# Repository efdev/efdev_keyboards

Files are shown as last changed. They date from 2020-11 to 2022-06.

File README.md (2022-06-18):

# PCBs

# Firmware

Based on zmk.

Basic setup see https://zmk.dev/docs/development/setup .

Extend zmk west.yml remotes list with the following 

```
- name: microsoft
      url-base: https://github.com/microsoft
```
and the projects list with
```
- name: uf2
      remote: microsoft
      path: tools/uf2
      clone-depth: 1
```
and run `west update`

Build firmware `west build -p -b <board> -- -DBOARD_ROOT=<path to cloned repo>/Firmware`

Example: `west build -p -b akortho -- -DBOARD_ROOT=/home/efdev/Documents/Keyboards/Firmware`

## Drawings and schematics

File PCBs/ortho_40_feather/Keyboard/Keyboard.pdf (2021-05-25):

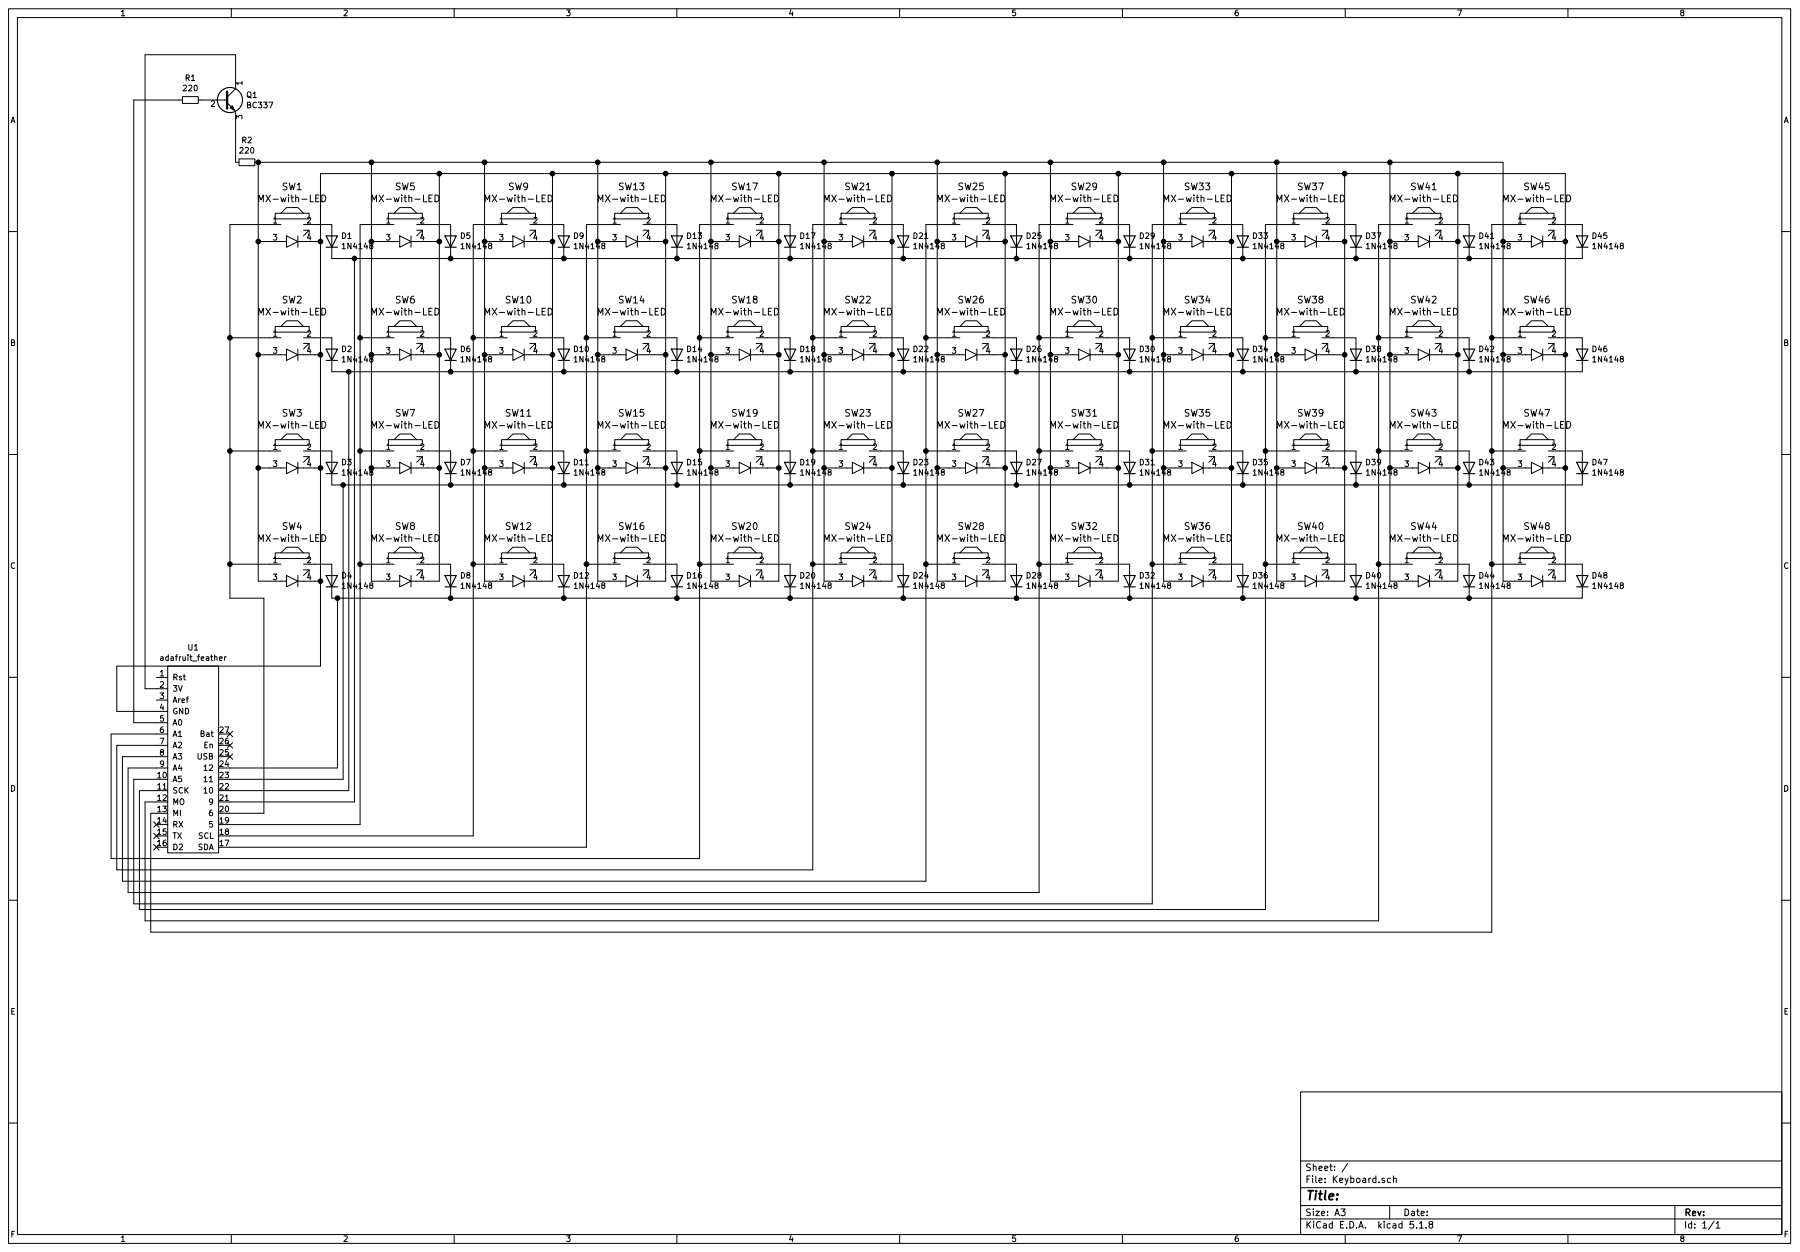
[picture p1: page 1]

File: Keyboard.sch Sheet: /

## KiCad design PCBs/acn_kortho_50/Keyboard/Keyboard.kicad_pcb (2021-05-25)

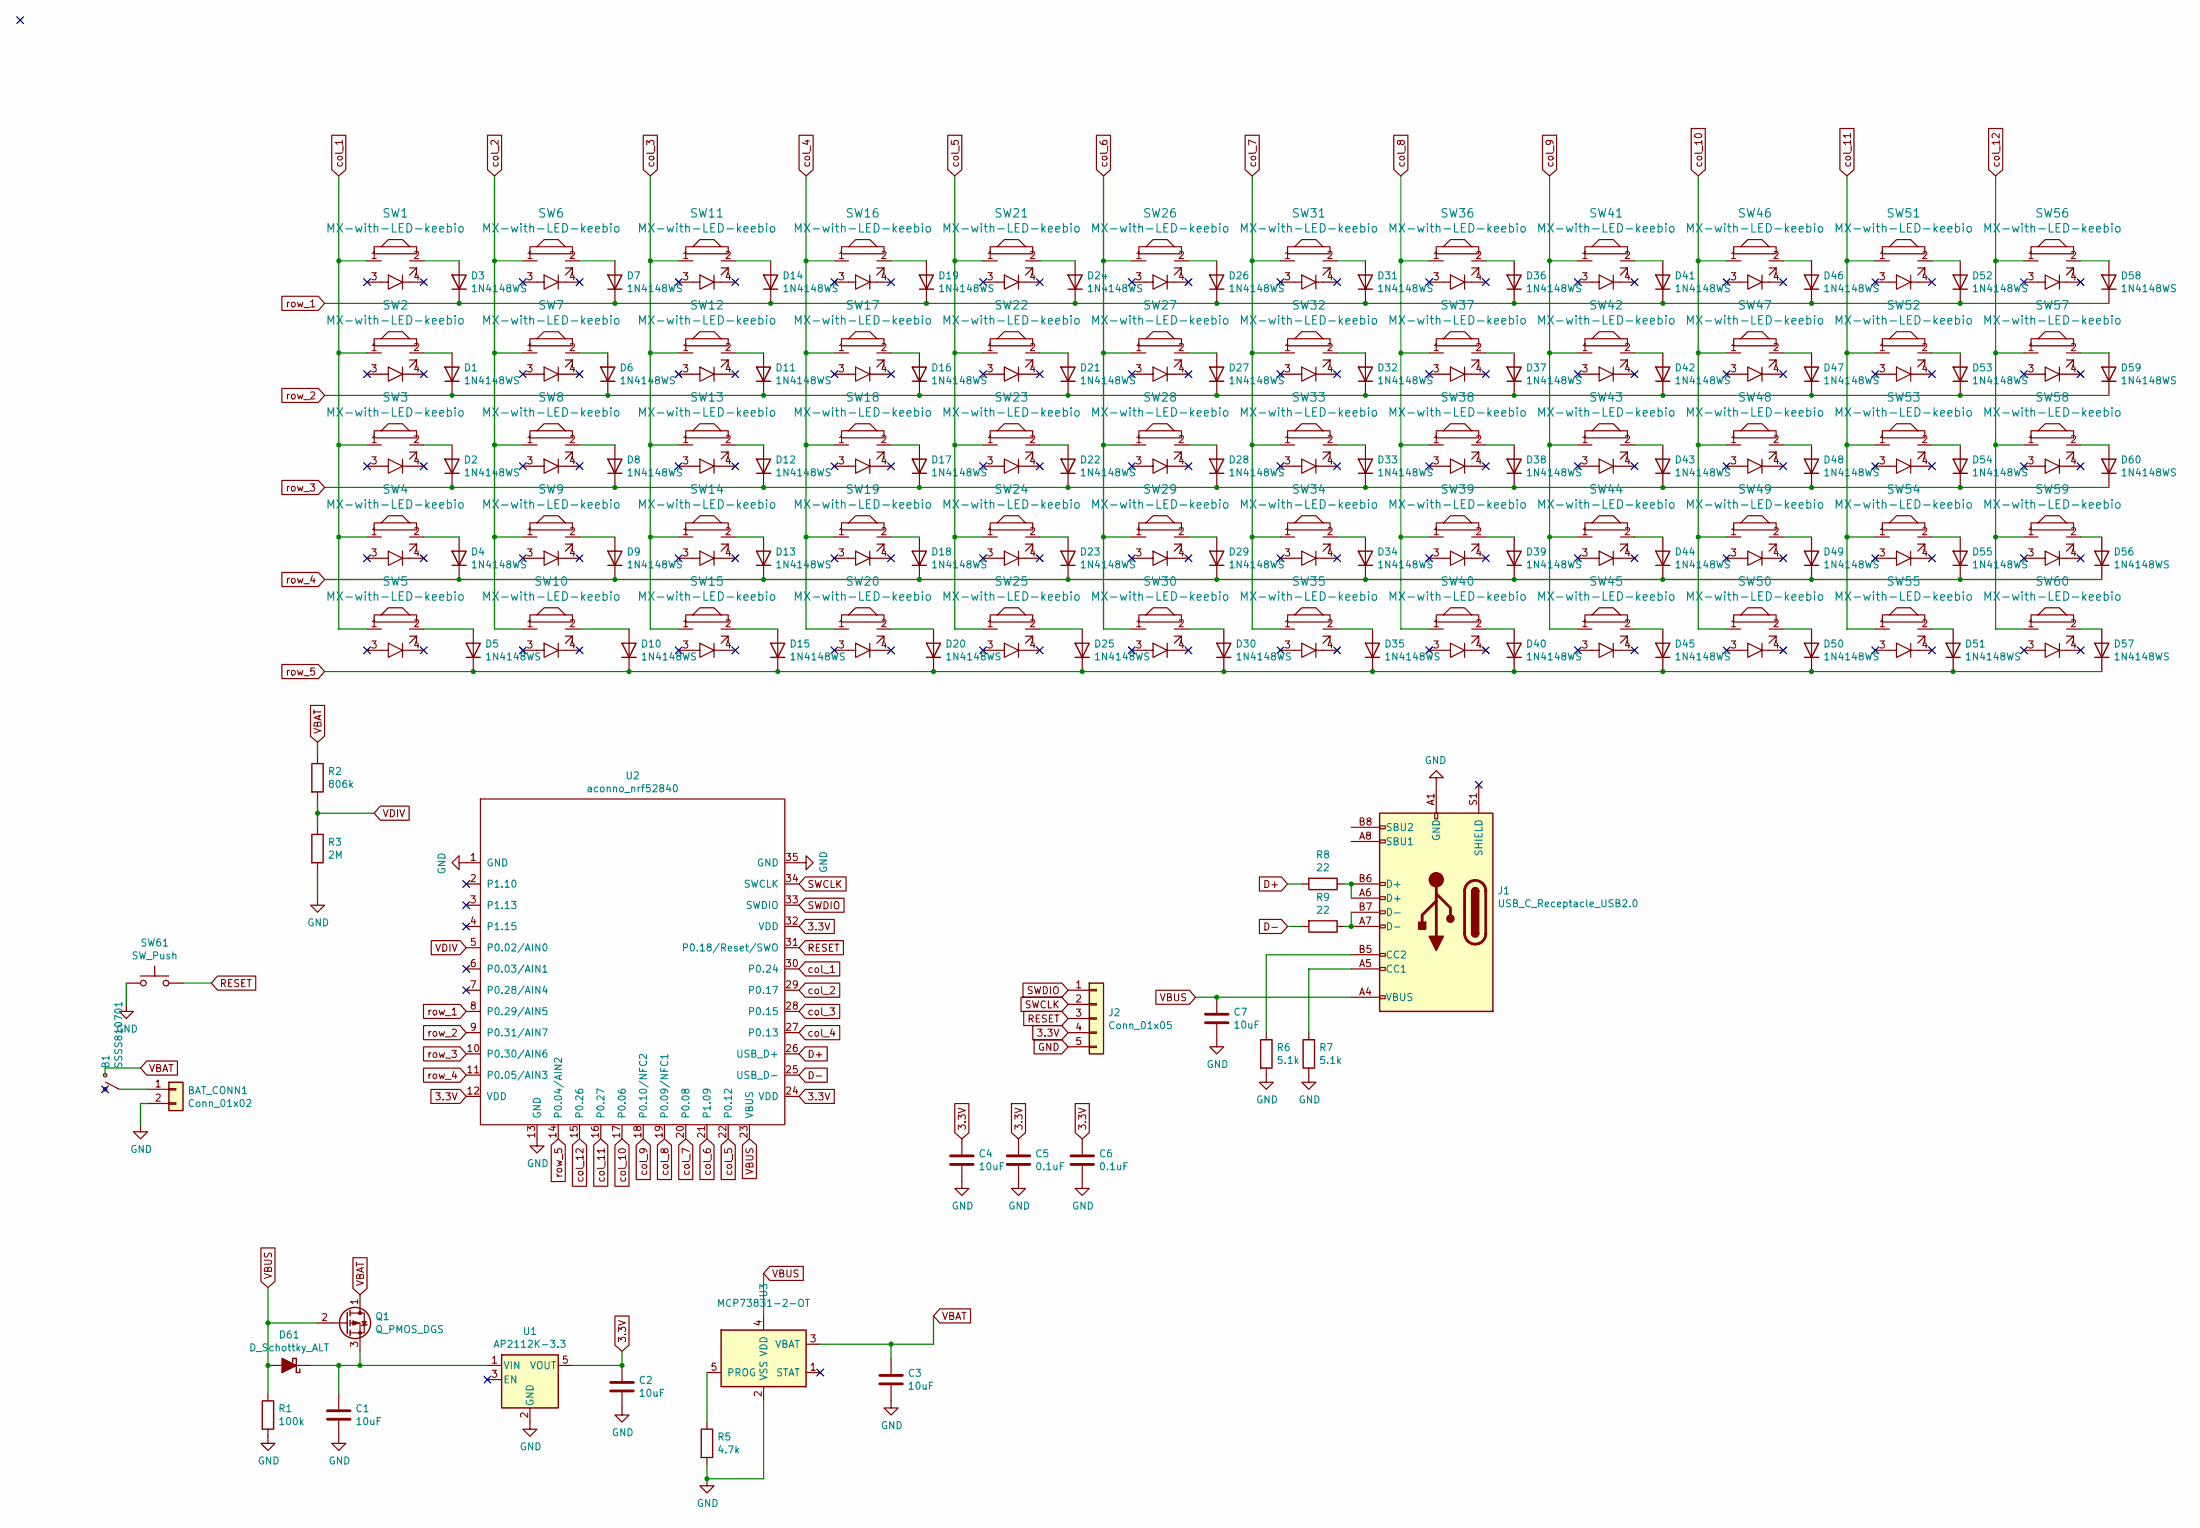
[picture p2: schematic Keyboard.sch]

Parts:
B1: SSSS810701
BAT_CONN1: Conn_01x02; PinHeader_1x02_P2.54mm_Vertical_SMD_Pin1Left
C1, C2, C3, C4, C7: 10uF; C_0603_1608Metric_Pad1.08x0.95mm_HandSolder
C5, C6: 0.1uF; C_0603_1608Metric_Pad1.08x0.95mm_HandSolder
D1, D2, D3, D4, D5, D6, D7, D8, D9, D10, D11, D12, D13, D14, D15, D16, D17, D18, D19, D20, D21, D22, D23, D24, D25, D26, D27, D28, D29, D30, D31, D32, D33, D34, D35, D36, D37, D38, D39, D40, D41, D42, D43, D44, D45, D46, D47, D48, D49, D50, D51, D52, D53, D54, D55, D56, D57, D58, D59, D60: 1N4148WS; D_SOD-323_HandSoldering
D61: D_Schottky_ALT; D_SOD-123F
J1: USB_C_Receptacle_USB2.0; USB_C_Receptacle_GCT_USB4085
J2: Conn_01x05; SWD
Q1: Q_PMOS_DGS; SOT-23_Handsoldering
R1: 100k; R_0603_1608Metric_Pad0.98x0.95mm_HandSolder
R2: 806k; R_0603_1608Metric_Pad0.98x0.95mm_HandSolder
R3: 2M; R_0603_1608Metric_Pad0.98x0.95mm_HandSolder
R5: 4.7k; R_0603_1608Metric_Pad0.98x0.95mm_HandSolder
R6, R7: 5.1k; R_0603_1608Metric_Pad0.98x0.95mm_HandSolder
R8, R9: 22; R_0603_1608Metric_Pad0.98x0.95mm_HandSolder
SW1, SW2, SW3, SW4, SW5, SW6, SW7, SW8, SW9, SW10, SW11, SW12, SW13, SW14, SW15, SW16, SW17, SW18, SW19, SW20, SW21, SW22, SW23, SW24, SW25, SW26, SW27, SW28, SW29, SW30, SW31, SW32, SW33, SW34, SW35, SW36, SW37, SW38, SW39, SW40, SW41, SW42, SW43, SW44, SW45, SW46, SW47, SW48, SW49, SW50, SW51, SW52, SW53, SW54, SW55, SW56, SW57, SW58, SW59, SW60: MX-with-LED-keebio; SW_Cherry_MX_1.00u_PCB
SW61: SW_Push; SW_Push_1P1T_NO_6x6mm_H9.5mm
U1: AP2112K-3.3; SOT-223
U2: aconno_nrf52840; aconno_nrf_52840_tht
U3: MCP73831-2-OT; SOT-23-5_HandSoldering

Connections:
3.3V: C2.1, C4.1, C5.1, C6.1, J2.4, U1.5 (VOUT), U2.12 (VDD), U2.24 (VDD), U2.32 (VDD)
D+: R8.2, U2.26 (USB_D+)
D-: R9.2, U2.25 (USB_D-)
GND: BAT_CONN1.2, C1.2, C2.2, C3.2, C4.2, C5.2, C6.2, C7.2, J1.A1 (GND), J1.A12 (GND), J1.B1 (GND), J1.B12 (GND), J1.S1 (SHIELD), J2.5, R1.2, R3.2, R5.2, R6.2, R7.1, SW61.1, U1.2 (GND), U2.1 (GND), U2.13 (GND), U2.35 (GND), U3.2 (VSS)
unnamed: B1.2, BAT_CONN1.1
unnamed: C1.1, D61.1 (K), Q1.3 (S), U1.1 (VIN)
unnamed: D1.2 (A), SW2.2
unnamed: D2.2 (A), SW3.2
unnamed: D3.2 (A), SW1.2
unnamed: D4.2 (A), SW4.2
unnamed: D5.2 (A), SW5.2
unnamed: D6.2 (A), SW7.2
unnamed: D7.2 (A), SW6.2
unnamed: D8.2 (A), SW8.2
unnamed: D9.2 (A), SW9.2
unnamed: D10.2 (A), SW10.2
unnamed: D11.2 (A), SW12.2
unnamed: D12.2 (A), SW13.2
unnamed: D13.2 (A), SW14.2
unnamed: D14.2 (A), SW11.2
unnamed: D15.2 (A), SW15.2
unnamed: D16.2 (A), SW17.2
unnamed: D17.2 (A), SW18.2
unnamed: D18.2 (A), SW19.2
unnamed: D19.2 (A), SW16.2
unnamed: D20.2 (A), SW20.2
unnamed: D21.2 (A), SW22.2
unnamed: D22.2 (A), SW23.2
unnamed: D23.2 (A), SW24.2
unnamed: D24.2 (A), SW21.2
unnamed: D25.2 (A), SW25.2
unnamed: D26.2 (A), SW26.2
unnamed: D27.2 (A), SW27.2
unnamed: D28.2 (A), SW28.2
unnamed: D29.2 (A), SW29.2
unnamed: D30.2 (A), SW30.2
unnamed: D31.2 (A), SW31.2
unnamed: D32.2 (A), SW32.2
unnamed: D33.2 (A), SW33.2
unnamed: D34.2 (A), SW34.2
unnamed: D35.2 (A), SW35.2
unnamed: D36.2 (A), SW36.2
unnamed: D37.2 (A), SW37.2
unnamed: D38.2 (A), SW38.2
unnamed: D39.2 (A), SW39.2
unnamed: D40.2 (A), SW40.2
unnamed: D41.2 (A), SW41.2
unnamed: D42.2 (A), SW42.2
unnamed: D43.2 (A), SW43.2
unnamed: D44.2 (A), SW44.2
unnamed: D45.2 (A), SW45.2
unnamed: D46.2 (A), SW46.2
unnamed: D47.2 (A), SW47.2
unnamed: D48.2 (A), SW48.2
unnamed: D49.2 (A), SW49.2
unnamed: D50.2 (A), SW50.2
unnamed: D51.2 (A), SW55.2
unnamed: D52.2 (A), SW51.2
unnamed: D53.2 (A), SW52.2
unnamed: D54.2 (A), SW53.2
unnamed: D55.2 (A), SW54.2
unnamed: D56.2 (A), SW59.2
unnamed: D57.2 (A), SW60.2
unnamed: D58.2 (A), SW56.2
unnamed: D59.2 (A), SW57.2
unnamed: D60.2 (A), SW58.2
unnamed: J1.A5 (CC1), R7.2
unnamed: J1.A6 (D+), J1.B6 (D+), R8.1
unnamed: J1.A7 (D-), J1.B7 (D-), R9.1
unnamed: J1.B5 (CC2), R6.1
unnamed: R5.1, U3.5 (PROG)
RESET: J2.3, SW61.2, U2.31 (P0.18/Reset/SWO)
SWCLK: J2.2, U2.34 (SWCLK)
SWDIO: J2.1, U2.33 (SWDIO)
VBAT: B1.1, C3.1, Q1.1 (D), R2.1, U3.3 (VBAT)
VBUS: C7.1, D61.2 (A), J1.A4 (VBUS), J1.A9 (VBUS), J1.B4 (VBUS), J1.B9 (VBUS), Q1.2 (G), R1.1, U2.23 (VBUS), U3.4 (VDD)
VDIV: R2.2, R3.1, U2.5 (P0.02/AIN0)
col_1: SW1.1, SW2.1, SW3.1, SW4.1, SW5.1, U2.30 (P0.24)
col_2: SW6.1, SW7.1, SW8.1, SW9.1, SW10.1, U2.29 (P0.17)
col_3: SW11.1, SW12.1, SW13.1, SW14.1, SW15.1, U2.28 (P0.15)
col_4: SW16.1, SW17.1, SW18.1, SW19.1, SW20.1, U2.27 (P0.13)
col_5: SW21.1, SW22.1, SW23.1, SW24.1, SW25.1, U2.22 (P0.12)
col_6: SW26.1, SW27.1, SW28.1, SW29.1, SW30.1, U2.21 (P1.09)
col_7: SW31.1, SW32.1, SW33.1, SW34.1, SW35.1, U2.20 (P0.08)
col_8: SW36.1, SW37.1, SW38.1, SW39.1, SW40.1, U2.19 (P0.09/NFC1)
col_9: SW41.1, SW42.1, SW43.1, SW44.1, SW45.1, U2.18 (P0.10/NFC2)
col_10: SW46.1, SW47.1, SW48.1, SW49.1, SW50.1, U2.17 (P0.06)
col_11: SW51.1, SW52.1, SW53.1, SW54.1, SW55.1, U2.16 (P0.27)
col_12: SW56.1, SW57.1, SW58.1, SW59.1, SW60.1, U2.15 (P0.26)
row_1: D3.1 (K), D7.1 (K), D14.1 (K), D19.1 (K), D24.1 (K), D26.1 (K), D31.1 (K), D36.1 (K), D41.1 (K), D46.1 (K), D52.1 (K), D58.1 (K), U2.8 (P0.29/AIN5)
row_2: D1.1 (K), D6.1 (K), D11.1 (K), D16.1 (K), D21.1 (K), D27.1 (K), D32.1 (K), D37.1 (K), D42.1 (K), D47.1 (K), D53.1 (K), D59.1 (K), U2.9 (P0.31/AIN7)
row_3: D2.1 (K), D8.1 (K), D12.1 (K), D17.1 (K), D22.1 (K), D28.1 (K), D33.1 (K), D38.1 (K), D43.1 (K), D48.1 (K), D54.1 (K), D60.1 (K), U2.10 (P0.30/AIN6)
row_4: D4.1 (K), D9.1 (K), D13.1 (K), D18.1 (K), D23.1 (K), D29.1 (K), D34.1 (K), D39.1 (K), D44.1 (K), D49.1 (K), D55.1 (K), D56.1 (K), U2.11 (P0.05/AIN3)
row_5: D5.1 (K), D10.1 (K), D15.1 (K), D20.1 (K), D25.1 (K), D30.1 (K), D35.1 (K), D40.1 (K), D45.1 (K), D50.1 (K), D51.1 (K), D57.1 (K), U2.14 (P0.04/AIN2)

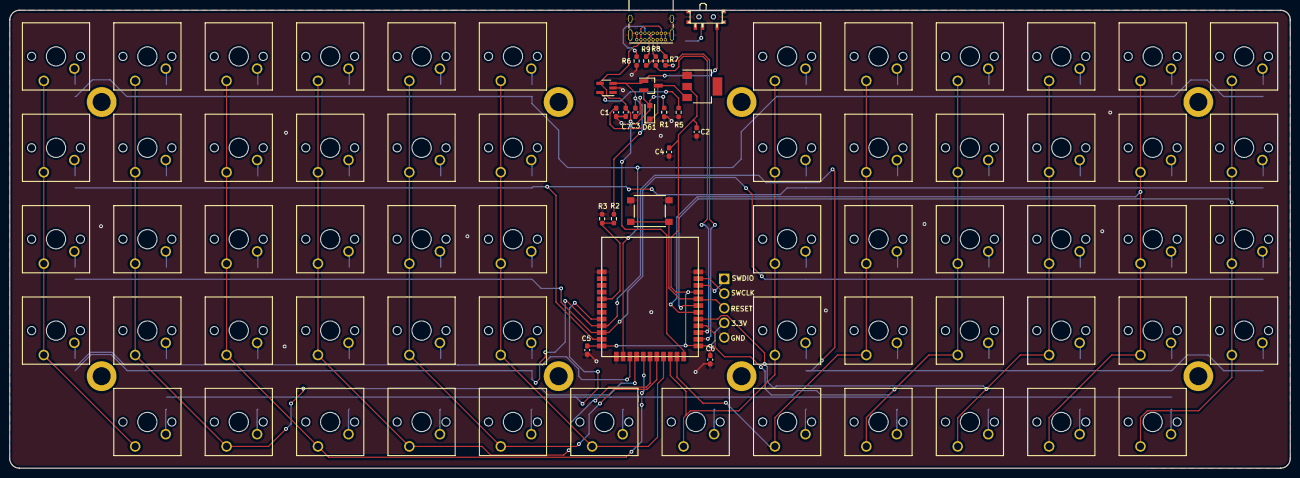
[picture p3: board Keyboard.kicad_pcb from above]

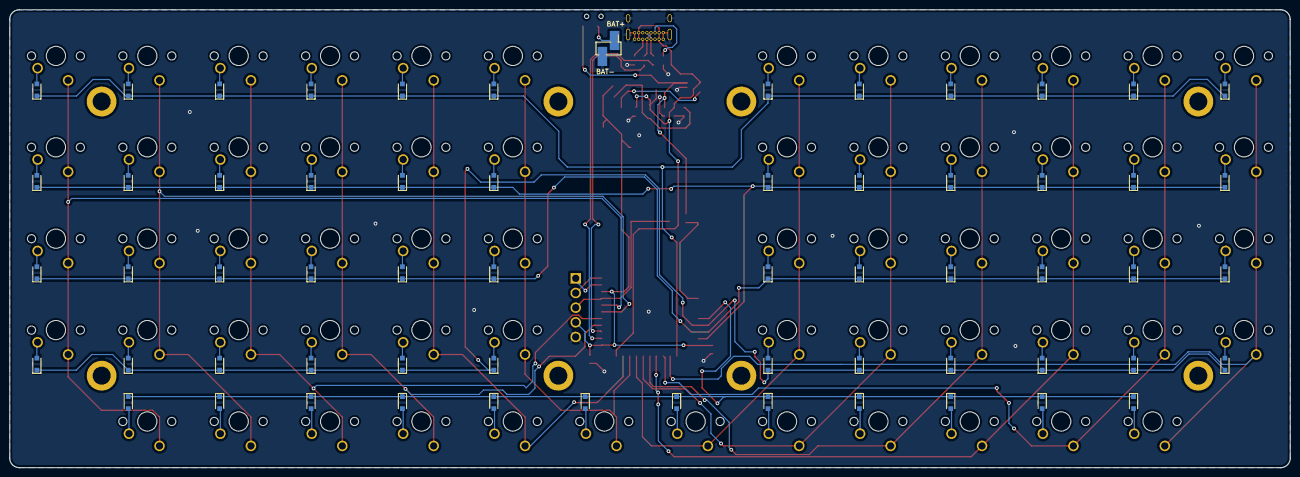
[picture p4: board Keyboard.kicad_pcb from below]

Board: 2 copper layers, 266.2 x 95.2 mm, 145 parts (61 on the bottom side), 94 nets.

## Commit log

2020-11-21 added backplate
    [backplate.kicad_pcb]
2020-11-21 added plate
    [plate_test.kicad_pcb]
2020-11-21 added keyboard
    [Keyboard.kicad_pcb, Keyboard.sch]
2020-11-21 changed footprint reference
2021-05-25 some stuff
    [Keyboard.kicad_pcb, Keyboard.sch, backplate.kicad_pcb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]
2022-06-18 Added board config
